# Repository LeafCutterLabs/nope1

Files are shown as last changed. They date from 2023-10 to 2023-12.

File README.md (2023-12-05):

# nope1
OP-1/LMN-3 interface based on the RP2040.<br>
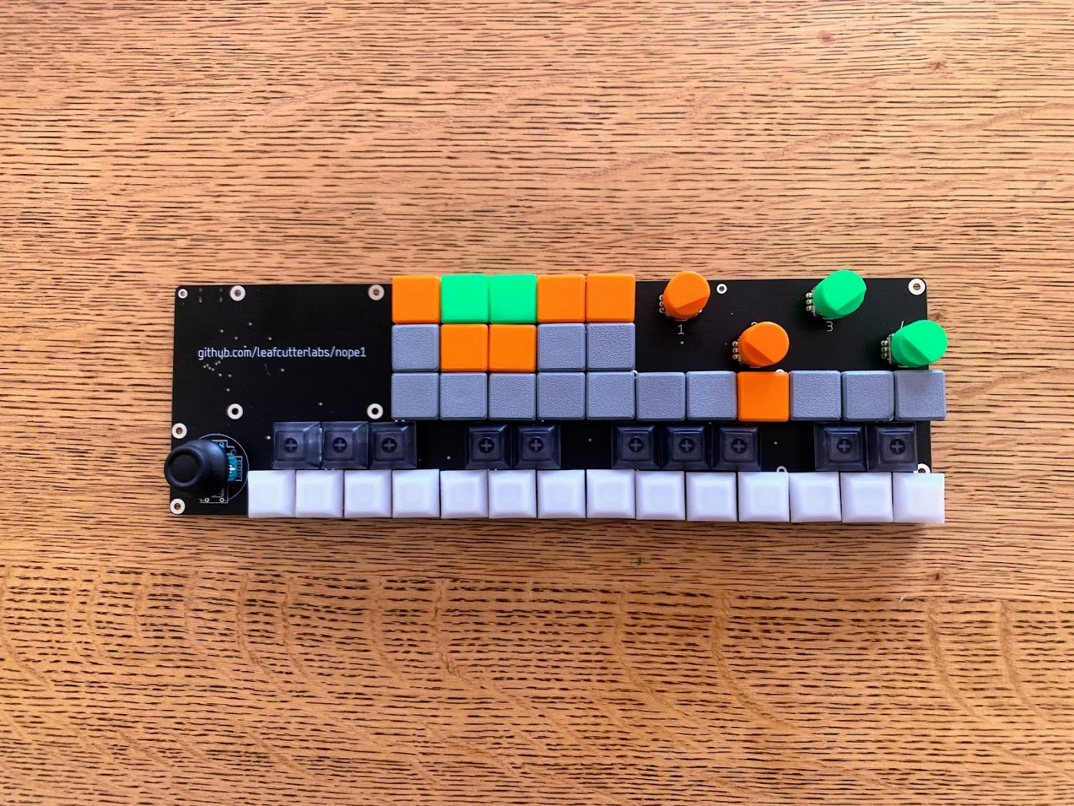
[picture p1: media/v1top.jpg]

Current QMK firmware is very basic (only midi keyboard implemented 53-76 and the LMN-3 CC signals, encoder are now working in vial! analog is not working)<br>
Joystick Analog pins: 26, 27<br>
Known Issues:<br>
	-Joystick switch trace is not connected<br>
 ToDo:<br>
 	-Get Vial running - DONE

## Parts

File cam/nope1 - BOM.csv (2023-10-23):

qty | designator | footprint | comment | lcsc | Value | Device | Package | Parts | Description | BOM | PROD_ID | REV
1 | USBJACK | USB-C-16P |  | C167321 |  |  |  |  | USB Type C 16Pin Connector |  | CONN-14122
9 | C6, C7, C9, C11, C12, C13, C14, C15, C16 | 0603-NO | 0.1uF |  |  |  |  |  | Ceramic Capacitors
4 | R1, R3, R4, R5 | 0603-NO | 10K |  |  |  |  |  | Resistors
3 | C1, C4, C5 | 0805-NO | 10uF |  |  |  |  |  | Ceramic Capacitors
1 | Y1 | RESONATOR3225 | 12MHz | C93234 |  |  |  |  | Various standard crystals. Proven footprints.
2 | R6, R11 | 0603-NO | 1K |  |  |  |  |  | Resistors
50 | U$13, U$14, U$15, U$17, U$18, U$19, U$20, U$21, U$22, U$23, U$24, U$26, U$27, U$28, U$29, U$30, U$31, U$32, U$33, U$54, U$59, U$63, U$68, U$69, U$70, U$71, U$94, U$95, U$96, U$97, U$99, U$100, U$101, U$102, U$103, U$104, U$105, U$106, U$108, U$109, U$110, U$111, U$134, U$135, U$136, U$137, U$139, U$140, U$141, U$142 | SOD-323SLIM | 1N4148WS
2 | C8, C10 | 0603-NO | 1uF |  |  |  |  |  | Ceramic Capacitors
2 | C2, C3 | 0603-NO | 22pF |  |  |  |  |  | Ceramic Capacitors
2 | R9, R10 | 0603-NO | 27 |  |  |  |  |  | Resistors
1 | U1 | SOIC8_208MIL | 2MB Flash | C97521 |  |  |  |  | SOIC8 SPI Flash
2 | R12, R13 | 0603-NO | 5.1K |  |  |  |  |  | Resistors
1 | U2 | SOT23-5@1 | AP2112-3.3 | C134139 |  |  |  |  | SOT23-5 Fixed Voltage Regulators
45 | SW00, SW01, SW02, SW03, SW04, SW09, SW10, SW11, SW12, SW13, SW14, SW15, SW16, SW17, SW18, SW19, SW20, SW21, SW22, SW23, SW24, SW25, SW26, SW27, SW28, SW29, SW30, SW31, SW32, SW33, SW34, SW35, SW36, SW37, SW38, SW39, SW41, SW42, SW43, SW44, SW45, SW46, SW47, SW48, SW49 | CHERRY-SOCKET5 | CHERRY-SOCKET7SOCKET5 | C5156480
4 | U$38, U$39, U$62, U$64 | FIDUCIAL_1MM | FIDUCIAL_1MM |  |  |  |  |  | Fiducial Alignment Points | EXCLUDE
1 | U$34 | JOYSTICKCOMBO | JOYSTICKCOMBO
15 | U$1, U$2, U$3, U$4, U$5, U$6, U$7, U$8, U$9, U$10, U$11, U$12, U$16, U$25, U$78 | M2MOUNT | M2MOUNT
8 | U$65, U$66, U$67, U$72, U$74, U$75, U$76, U$77 | M2SOLDER | M2MOUNTSOLDERMOUNT | C2928180
1 | D4 | SOD-123 | MBR540 | C8598
1 | U$73 | PI4 | PI4
4 | ROT0, ROT1, ROT2, ROT3 | ROTARY_ENC_SLOT | ROTARYENCODER_UNIVERSALSLOT
1 | IC1 | QFN56_7MM_REDUCEDEPAD | RP2040_QFN56
2 | RST, USB | TACTILE_SWITCH_SMD | SWITCH-MOMENTARY-2SMD | C318884 |  |  |  |  | Various NO switches- pushbuttons, reed, etc |  | SWCH-08247

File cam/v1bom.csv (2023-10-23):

Qty | Value | Device | Package | Parts | Description | BOM | PROD_ID | REV
1 |  | USB_C16PIN | USB-C-16P | USBJACK | USB Type C 16Pin Connector |  | CONN-14122
9 | 0.1uF | CAP_CERAMIC0603_NO | 0603-NO | C6, C7, C9, C11, C12, C13, C14, C15, C16 | Ceramic Capacitors
4 | 10K | RESISTOR_0603_NOOUT | 0603-NO | R1, R3, R4, R5 | Resistors
1 | 10uF | CAP_CERAMIC0805-NOOUTLINE | 0805-NO | C5 | Ceramic Capacitors
1 | 10µF | CAP_CERAMIC0805-NOOUTLINE | 0805-NO | C1 | Ceramic Capacitors
1 | 10µF | CAP_CERAMIC0805-NOOUTLINE | 0805-NO | C4 | Ceramic Capacitors |  |  | A
1 | 12MHz | CRYSTAL | RESONATOR3225 | Y1 | Various standard crystals. Proven footprints.
2 | 1K | RESISTOR_0603_NOOUT | 0603-NO | R6, R11 | Resistors
50 | 1N4148WS | 1N4148WS | SOD-323SLIM | U$13, U$14, U$15, U$17, U$18, U$19, U$20, U$21, U$22, U$23, U$24, U$26, U$27, U$28, U$29, U$30, U$31, U$32, U$33, U$54, U$59, U$63, U$68, U$69, U$70, U$71, U$94, U$95, U$96, U$97, U$99, U$100, U$101, U$102, U$103, U$104, U$105, U$106, U$108, U$109, U$110, U$111, U$134, U$135, U$136, U$137, U$139, U$140, U$141, U$142
2 | 1uF | CAP_CERAMIC0603_NO | 0603-NO | C8, C10 | Ceramic Capacitors
2 | 22pF | CAP_CERAMIC0603_NO | 0603-NO | C2, C3 | Ceramic Capacitors
2 | 27 | RESISTOR_0603_NOOUT | 0603-NO | R9, R10 | Resistors
1 | 2MB Flash | SPIFLASH_8PIN208MIL | SOIC8_208MIL | U1 | SOIC8 SPI Flash
2 | 5.1K | RESISTOR_0603_NOOUT | 0603-NO | R12, R13 | Resistors
1 | AP2112-3.3 | VREG_SOT23-5 | SOT23-5@1 | U2 | SOT23-5 Fixed Voltage Regulators
45 | CHERRY-SOCKET7SOCKET5 | CHERRY-SOCKET7SOCKET5 | CHERRY-SOCKET5 | SW00, SW01, SW02, SW03, SW04, SW09, SW10, SW11, SW12, SW13, SW14, SW15, SW16, SW17, SW18, SW19, SW20, SW21, SW22, SW23, SW24, SW25, SW26, SW27, SW28, SW29, SW30, SW31, SW32, SW33, SW34, SW35, SW36, SW37, SW38, SW39, SW41, SW42, SW43, SW44, SW45, SW46, SW47, SW48, SW49
4 | FIDUCIAL_1MM | FIDUCIAL_1MM | FIDUCIAL_1MM | U$38, U$39, U$62, U$64 | Fiducial Alignment Points | EXCLUDE
1 | JOYSTICKCOMBO | JOYSTICKCOMBO | JOYSTICKCOMBO | U$34
15 | M2MOUNT | M2MOUNT | M2MOUNT | U$1, U$2, U$3, U$4, U$5, U$6, U$7, U$8, U$9, U$10, U$11, U$12, U$16, U$25, U$78
8 | M2MOUNTSOLDERMOUNT | M2MOUNTSOLDERMOUNT | M2SOLDER | U$65, U$66, U$67, U$72, U$74, U$75, U$76, U$77
1 | MBR540 | DIODE-SCHOTTKYSOD-123 | SOD-123 | D4
1 | PI4 | PI4 | PI4 | U$73
4 | ROTARYENCODER_UNIVERSALSLOT | ROTARYENCODER_UNIVERSALSLOT | ROTARY_ENC_SLOT | ROT0, ROT1, ROT2, ROT3
1 | RP2040_QFN56 | RP2040_QFN56 | QFN56_7MM_REDUCEDEPAD | IC1
2 | SWITCH-MOMENTARY-2SMD | SWITCH-MOMENTARY-2SMD | TACTILE_SWITCH_SMD | RST, USB | Various NO switches- pushbuttons, reed, etc |  | SWCH-08247

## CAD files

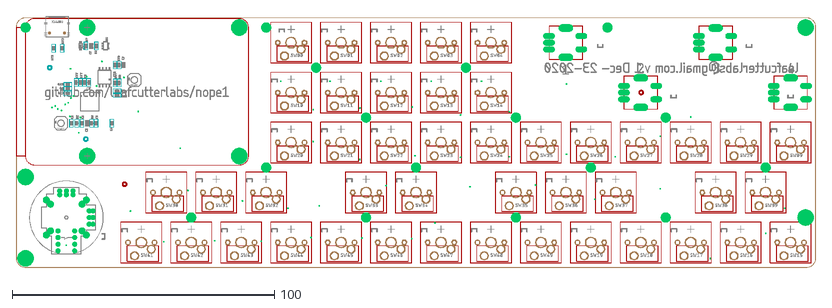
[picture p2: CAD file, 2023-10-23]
cad/v1.dxf
305.0 x 95.9

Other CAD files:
cad/v1CLEAN.dxf

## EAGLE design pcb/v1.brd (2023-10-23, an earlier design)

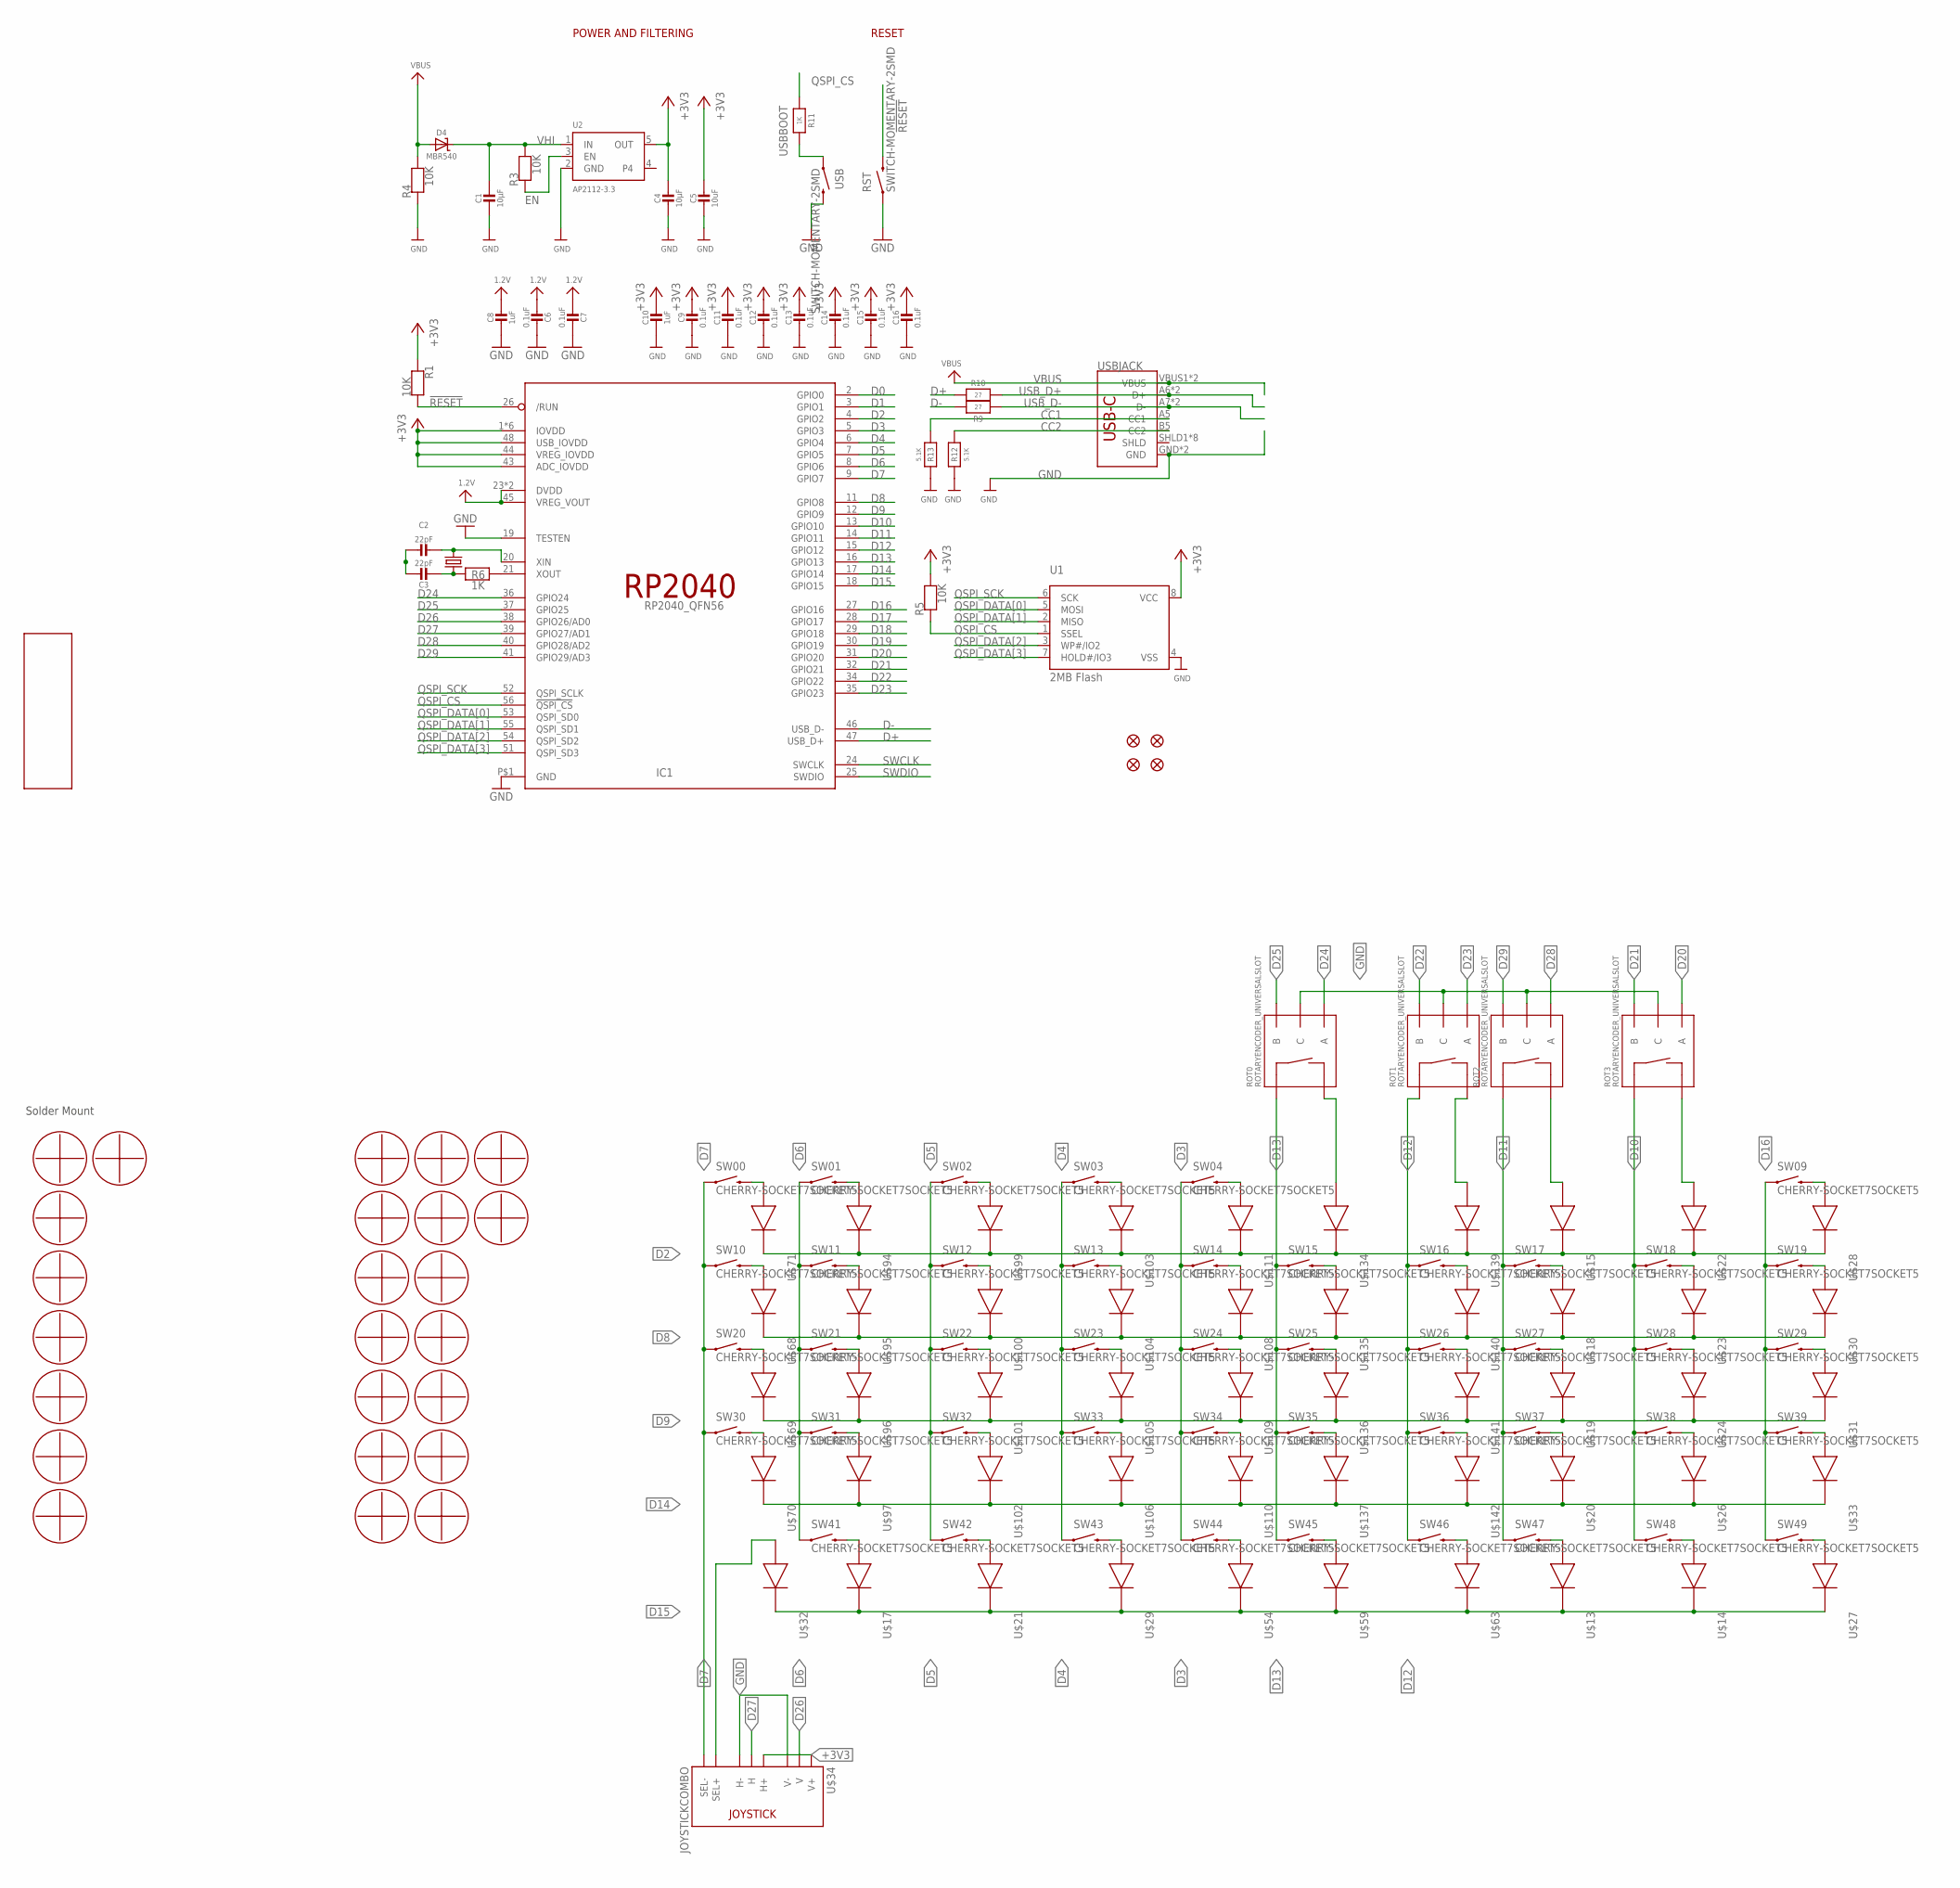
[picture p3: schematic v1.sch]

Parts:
C1, C4: 10µF; 0805-NO
C2, C3: 22pF; 0603-NO
C5: 10uF; 0805-NO
C6, C7, C9, C11, C12, C13, C14, C15, C16: 0.1uF; 0603-NO
C8, C10: 1uF; 0603-NO
D4: MBR540; SOD-123
IC1: RP2040_QFN56; QFN56_7MM_REDUCEDEPAD
R1, R3, R4, R5: 10K; 0603-NO
R6, R11: 1K; 0603-NO
R9, R10: 27; 0603-NO
R12, R13: 5.1K; 0603-NO
ROT0, ROT1, ROT2, ROT3: ROTARYENCODER_UNIVERSALSLOT; ROTARY_ENC_SLOT
RST: SWITCH-MOMENTARY-2SMD; TACTILE_SWITCH_SMD
SW00, SW01, SW02, SW03, SW04, SW09, SW10, SW11, SW12, SW13, SW14, SW15, SW16, SW17, SW18, SW19, SW20, SW21, SW22, SW23, SW24, SW25, SW26, SW27, SW28, SW29, SW30, SW31, SW32, SW33, SW34, SW35, SW36, SW37, SW38, SW39, SW41, SW42, SW43, SW44, SW45, SW46, SW47, SW48, SW49: CHERRY-SOCKET7SOCKET5; CHERRY-SOCKET5
U1: 2MB Flash; SOIC8_208MIL
U2: AP2112-3.3; SOT23-5@1
U$1, U$2, U$3, U$4, U$5, U$6, U$7, U$8, U$9, U$10, U$11, U$12, U$16, U$25, U$78, U$79: M2MOUNT
U$13, U$14, U$15, U$17, U$18, U$19, U$20, U$21, U$22, U$23, U$24, U$26, U$27, U$28, U$29, U$30, U$31, U$32, U$33, U$54, U$59, U$63, U$68, U$69, U$70, U$71, U$94, U$95, U$96, U$97, U$99, U$100, U$101, U$102, U$103, U$104, U$105, U$106, U$108, U$109, U$110, U$111, U$134, U$135, U$136, U$137, U$139, U$140, U$141, U$142: 1N4148WS; SOD-323SLIM
U$34: JOYSTICKCOMBO
U$38, U$39, U$62, U$64: FIDUCIAL_1MM
U$65, U$66, U$67, U$72, U$74, U$75, U$76, U$77: M2MOUNTSOLDERMOUNT; M2SOLDER
U$73: PI4
USB: SWITCH-MOMENTARY-2SMD; TACTILE_SWITCH_SMD
USBJACK: USB_C16PIN; USB-C-16P
Y1: 12MHz; RESONATOR3225

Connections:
1.2V: C6.2, C7.2, C8.1, IC1.23 (DVDD), IC1.45 (VREG_VOUT), IC1.50 (DVDD)
!RESET: IC1.26 (/RUN), R1.2, RST.3 (2)
+3V3: C4.1, C5.1, C9.1, C10.1, C11.1, C12.1, C13.1, C14.1, C15.1, C16.1, IC1.1 (IOVDD), IC1.10 (IOVDD), IC1.22 (IOVDD), IC1.33 (IOVDD), IC1.42 (IOVDD), IC1.43 (ADC_IOVDD), IC1.44 (VREG_IOVDD), IC1.48 (USB_IOVDD), IC1.49 (IOVDD), R1.1, R5.2, U1.8 (VCC), U2.5 (OUT), U$34.H1 (H+), U$34.HS1 (H+), U$34.V1 (V+), U$34.VS1 (V+)
CC1: R13.2, USBJACK.A5 (CC1)
CC2: R12.2, USBJACK.B5 (CC2)
D0: IC1.2 (GPIO0)
D1: IC1.3 (GPIO1)
D2: IC1.4 (GPIO2), U$15.GND (CAT), U$22.GND (CAT), U$28.GND (CAT), U$71.GND (CAT), U$94.GND (CAT), U$99.GND (CAT), U$103.GND (CAT), U$111.GND (CAT), U$134.GND (CAT), U$139.GND (CAT)
D3: IC1.5 (GPIO3), SW04.A (1), SW14.A (1), SW24.A (1), SW34.A (1), SW44.A (1)
D4: IC1.6 (GPIO4), SW03.A (1), SW13.A (1), SW23.A (1), SW33.A (1), SW43.A (1)
D5: IC1.7 (GPIO5), SW02.A (1), SW12.A (1), SW22.A (1), SW32.A (1), SW42.A (1)
D6: IC1.8 (GPIO6), SW01.A (1), SW11.A (1), SW21.A (1), SW31.A (1), SW41.A (1)
D7: IC1.9 (GPIO7), SW00.A (1), SW10.A (1), SW20.A (1), SW30.A (1), U$34.B1B (SEL-), U$34.B1B1 (SEL-), U$34.B2B (SEL-), U$34.B2B1 (SEL-)
D8: IC1.11 (GPIO8), U$18.GND (CAT), U$23.GND (CAT), U$30.GND (CAT), U$68.GND (CAT), U$95.GND (CAT), U$100.GND (CAT), U$104.GND (CAT), U$108.GND (CAT), U$135.GND (CAT), U$140.GND (CAT)
D9: IC1.12 (GPIO9), U$19.GND (CAT), U$24.GND (CAT), U$31.GND (CAT), U$69.GND (CAT), U$96.GND (CAT), U$101.GND (CAT), U$105.GND (CAT), U$109.GND (CAT), U$136.GND (CAT), U$141.GND (CAT)
D10: IC1.13 (GPIO10), ROT3.SW+, SW18.A (1), SW28.A (1), SW38.A (1), SW48.A (1)
D11: IC1.14 (GPIO11), ROT2.SW+, SW17.A (1), SW27.A (1), SW37.A (1), SW47.A (1)
D12: IC1.15 (GPIO12), ROT1.SW+, SW16.A (1), SW26.A (1), SW36.A (1), SW46.A (1)
D13: IC1.16 (GPIO13), ROT0.SW+, SW15.A (1), SW25.A (1), SW35.A (1), SW45.A (1)
D14: IC1.17 (GPIO14), U$20.GND (CAT), U$26.GND (CAT), U$33.GND (CAT), U$70.GND (CAT), U$97.GND (CAT), U$102.GND (CAT), U$106.GND (CAT), U$110.GND (CAT), U$137.GND (CAT), U$142.GND (CAT)
D15: IC1.18 (GPIO15), U$13.GND (CAT), U$14.GND (CAT), U$17.GND (CAT), U$21.GND (CAT), U$27.GND (CAT), U$29.GND (CAT), U$32.GND (CAT), U$54.GND (CAT), U$59.GND (CAT), U$63.GND (CAT)
D16: IC1.27 (GPIO16), SW09.A (1), SW19.A (1), SW29.A (1), SW39.A (1), SW49.A (1)
D17: IC1.28 (GPIO17)
D18: IC1.29 (GPIO18)
D19: IC1.30 (GPIO19)
D20: IC1.31 (GPIO20), ROT3.A
D21: IC1.32 (GPIO21), ROT3.B
D22: IC1.34 (GPIO22), ROT1.B
D23: IC1.35 (GPIO23), ROT1.A
D24: IC1.36 (GPIO24), ROT0.A
D25: IC1.37 (GPIO25), ROT0.B
D26: IC1.38 (GPIO26/AD0), U$34.V2 (V), U$34.VS2 (V)
D27: IC1.39 (GPIO27/AD1), U$34.H2 (H), U$34.HS2 (H)
D28: IC1.40 (GPIO28/AD2), ROT2.A
D29: IC1.41 (GPIO29/AD3), ROT2.B
D+: IC1.47 (USB_D+), R10.2
D-: IC1.46 (USB_D-), R9.2
EN: R3.1, U2.3 (EN)
GND: C1.2, C2.1, C3.1, C4.2, C5.2, C6.1, C7.1, C8.2, C9.2, C10.2, C11.2, C12.2, C13.2, C14.2, C15.2, C16.2, IC1.19 (TESTEN), IC1.P$1 (GND), R4.1, R12.1, R13.1, ROT0.C, ROT1.C, ROT2.C, ROT3.C, RST.1, U1.4 (VSS), U2.2 (GND), U$34.H3 (H-), U$34.HS3 (H-), U$34.V3 (V-), U$34.VS3 (V-), USB.3 (2), USBJACK.GND, USBJACK.GND2 (GND)
unnamed: U$32.SIGNAL (ANO), U$34.B1A (SEL+), U$34.B1A1 (SEL+), U$34.B2A (SEL+), U$34.B2A1 (SEL+)
unnamed: SW47.B (2), U$13.SIGNAL (ANO)
unnamed: SW48.B (2), U$14.SIGNAL (ANO)
unnamed: ROT2.SW-, U$15.SIGNAL (ANO)
unnamed: SW17.B (2), U$18.SIGNAL (ANO)
unnamed: SW27.B (2), U$19.SIGNAL (ANO)
unnamed: SW37.B (2), U$20.SIGNAL (ANO)
unnamed: SW41.B (2), U$17.SIGNAL (ANO)
unnamed: ROT3.SW-, U$22.SIGNAL (ANO)
unnamed: SW18.B (2), U$23.SIGNAL (ANO)
unnamed: SW28.B (2), U$24.SIGNAL (ANO)
unnamed: SW38.B (2), U$26.SIGNAL (ANO)
unnamed: SW49.B (2), U$27.SIGNAL (ANO)
unnamed: SW09.B (2), U$28.SIGNAL (ANO)
unnamed: SW42.B (2), U$21.SIGNAL (ANO)
unnamed: SW19.B (2), U$30.SIGNAL (ANO)
unnamed: SW29.B (2), U$31.SIGNAL (ANO)
unnamed: SW39.B (2), U$33.SIGNAL (ANO)
unnamed: SW00.B (2), U$71.SIGNAL (ANO)
unnamed: C2.2, IC1.20 (XIN), Y1.P3 (2)
unnamed: SW43.B (2), U$29.SIGNAL (ANO)
unnamed: SW44.B (2), U$54.SIGNAL (ANO)
unnamed: C3.2, R6.1, Y1.P1 (1)
unnamed: IC1.21 (XOUT), R6.2
unnamed: SW45.B (2), U$59.SIGNAL (ANO)
unnamed: SW10.B (2), U$68.SIGNAL (ANO)
unnamed: SW20.B (2), U$69.SIGNAL (ANO)
unnamed: SW30.B (2), U$70.SIGNAL (ANO)
unnamed: SW46.B (2), U$63.SIGNAL (ANO)
unnamed: SW01.B (2), U$94.SIGNAL (ANO)
unnamed: SW11.B (2), U$95.SIGNAL (ANO)
unnamed: SW21.B (2), U$96.SIGNAL (ANO)
unnamed: SW31.B (2), U$97.SIGNAL (ANO)
unnamed: SW02.B (2), U$99.SIGNAL (ANO)
unnamed: SW12.B (2), U$100.SIGNAL (ANO)
unnamed: SW22.B (2), U$101.SIGNAL (ANO)
unnamed: SW32.B (2), U$102.SIGNAL (ANO)
unnamed: SW14.B (2), U$108.SIGNAL (ANO)
unnamed: SW24.B (2), U$109.SIGNAL (ANO)
unnamed: SW34.B (2), U$110.SIGNAL (ANO)
unnamed: SW03.B (2), U$103.SIGNAL (ANO)
unnamed: SW13.B (2), U$104.SIGNAL (ANO)
unnamed: SW23.B (2), U$105.SIGNAL (ANO)
unnamed: SW33.B (2), U$106.SIGNAL (ANO)
unnamed: SW04.B (2), U$111.SIGNAL (ANO)
unnamed: ROT0.SW-, U$134.SIGNAL (ANO)
unnamed: SW15.B (2), U$135.SIGNAL (ANO)
unnamed: SW25.B (2), U$136.SIGNAL (ANO)
unnamed: SW35.B (2), U$137.SIGNAL (ANO)
unnamed: ROT1.SW-, U$139.SIGNAL (ANO)
unnamed: SW16.B (2), U$140.SIGNAL (ANO)
unnamed: SW26.B (2), U$141.SIGNAL (ANO)
unnamed: SW36.B (2), U$142.SIGNAL (ANO)
QSPI_CS: IC1.56 (!QSPI_CS), R5.1, R11.1, U1.1 (SSEL)
QSPI_DATA[0]: IC1.53 (QSPI_SD0), U1.5 (MOSI)
QSPI_DATA[1]: IC1.55 (QSPI_SD1), U1.2 (MISO)
QSPI_DATA[2]: IC1.54 (QSPI_SD2), U1.3 (WP#/IO2)
QSPI_DATA[3]: IC1.51 (QSPI_SD3), U1.7 (HOLD#/IO3)
QSPI_SCK: IC1.52 (QSPI_SCLK), U1.6 (SCK)
SWCLK: IC1.24 (SWCLK)
SWDIO: IC1.25 (SWDIO)
USBBOOT: R11.2, USB.1
USB_D+: R10.1, USBJACK.A6 (D+), USBJACK.B6 (D+)
USB_D-: R9.1, USBJACK.A7 (D-), USBJACK.B7 (D-)
VBUS: D4.A, R4.2, USBJACK.VBUS1 (VBUS), USBJACK.VBUS2 (VBUS)
VHI: C1.1, D4.C, R3.2, U2.1 (IN)

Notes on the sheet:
POWER AND FILTERING
RESET
Solder Mount

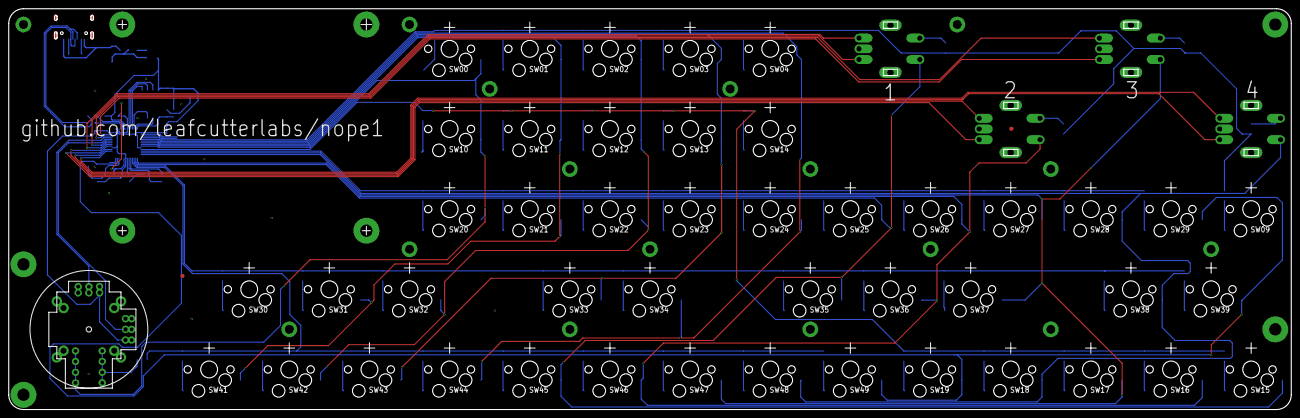
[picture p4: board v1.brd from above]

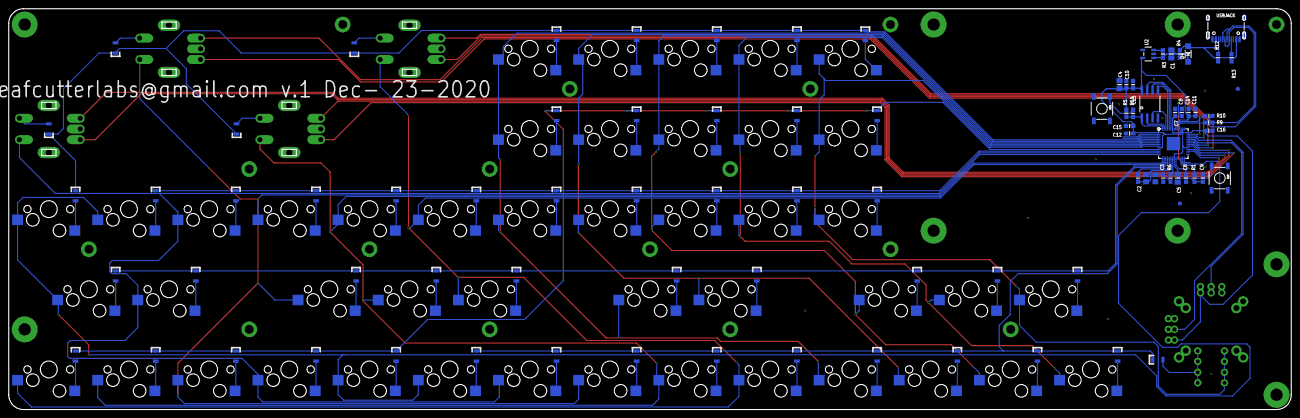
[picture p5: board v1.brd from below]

Board: 2 copper layers, 304.8 x 95.2 mm, 163 parts (94 on the bottom side), 98 nets.

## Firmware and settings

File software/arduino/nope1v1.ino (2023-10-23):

#include <Control_Surface.h>

// Instantiate a MIDI over USB interface.
USBMIDI_Interface midi;

CCPotentiometer pot0 { A0, MIDI_CC::General_Purpose_Controller_1 }; //joystick up/down
CCPotentiometer pot1 { A1, MIDI_CC::General_Purpose_Controller_2 }; //joystick left/right

const int ENCODER_1 = 3;
const int ENCODER_2 = 9;
const int ENCODER_3 = 14;
const int ENCODER_4 = 15;

// Row Pins
const int ROW_0 = 2;
const int ROW_1 = 8;
const int ROW_2 = 9;
const int ROW_3 = 14;
const int ROW_4 = 15;

// Col Pins
const int COL_0 = 7;
const int COL_1 = 6;
const int COL_2 = 5;
const int COL_3 = 4;
const int COL_4 = 3;
const int COL_5 = 13;
const int COL_6 = 12;
const int COL_7 = 11;
const int COL_8 = 10;
const int COL_9 = 16;

CCRotaryEncoder enc1 = {
    {24, 25}, // pins
    {ENCODER_1},         // MIDI address (CC number + optional channel)
    1,      // optional multiplier if the control isn't fast enough
};

CCRotaryEncoder enc2 = {
    {23, 22}, // pins
    {ENCODER_2},         // MIDI address (CC number + optional channel)
    1,      // optional multiplier if the control isn't fast enough
};

CCRotaryEncoder enc3 = {
    {28, 29}, // pins
    {ENCODER_3},         // MIDI address (CC number + optional channel)
    1,      // optional multiplier if the control isn't fast enough
};

CCRotaryEncoder enc4 = {
    {20, 21}, // pins
    {ENCODER_4},         // MIDI address (CC number + optional channel)
    1,      // optional multiplier if the control isn't fast enough
};

const AddressMatrix<3, 10> noteAddresses = {{
                                                {1 ,  1,  1,  1, 1 , 76, 74, 72, 71, 69},
                                                {54, 56, 58, 61, 63, 66, 68, 70, 73, 75},
                                                {1 , 53, 55, 57, 59, 60, 62, 64, 65, 67},  
                                            }};

NoteButtonMatrix<3, 10> noteButtonMatrix = {
    {ROW_2, ROW_3, ROW_4}, // row pins
    {COL_0, COL_1, COL_2, COL_3, COL_4, COL_5, COL_6, COL_7, COL_8, COL_9},    // column pins
    noteAddresses,    // address matrix
    CHANNEL_1,    // channel and cable number
};

void setup() {
    Control_Surface.begin(); // Initialize Control Surface
}

void loop() {
    Control_Surface.loop(); // Update the Control Surface
}

/*
// CC values
const int ENCODER_1 = 3;
const int ENCODER_2 = 9;
const int ENCODER_3 = 14;
const int ENCODER_4 = 15;
const int ENCODER_1_BUTTON = 20;
const int ENCODER_2_BUTTON = 21;
const int ENCODER_3_BUTTON = 22;
const int ENCODER_4_BUTTON = 23;
const int UNDO_BUTTON = 24;
const int TEMPO_BUTTON = 25;
const int SAVE_BUTTON = 26;
const int SETTINGS_BUTTON = 85;
const int TRACKS_BUTTON = 86;
const int MIXER_BUTTON = 88;
const int PLUGINS_BUTTON = 89;
const int MODIFIERS_BUTTON = 90;
const int SEQUENCERS_BUTTON = 102;   
const int LOOP_IN_BUTTON = 103;
const int LOOP_OUT_BUTTON = 104;
const int LOOP_BUTTON = 105;
const int CUT_BUTTON = 106;
const int PASTE_BUTTON = 107;
const int SLICE_BUTTON = 108;
const int RECORD_BUTTON = 109;
const int PLAY_BUTTON = 110;
const int STOP_BUTTON = 111;
const int CONTROL_BUTTON = 112;
const int OCTAVE_CHANGE = 117;
const int PLUS_BUTTON = 118;
const int MINUS_BUTTON = 119;
const int DUMMY = 31;


const AddressMatrix<5, 10> noteAddresses = {{
                                                {50, 51, 52, 53, 54, 55, 56, 57, 58, 59},
                                                {60, 61, 62, 63, 64, 65, 66, 67, 68, 69},
                                                {70, 71, 72, 73, 74, 75, 76, 77, 78, 79},
                                                {80, 81, 82, 83, 84, 85, 86, 87, 88, 89},
                                                {90, 91, 92, 93, 94, 95, 96, 97, 98, 99},  
                                            }};

Bankable::NoteButtonMatrix<2, 14> noteButtonMatrix = {
    transposer,
    {ROW_1, ROW_2, ROW_3, ROW_4, ROW_5}, // row pins
    {COL_0, COL_1, COL_2, COL_3, COL_4, COL_5, COL_6, COL_7, COL_8, COL_9},    // column pins
    noteAddresses,    // address matrix
    CHANNEL_1,    // channel and cable number
};


/*
const int maxTransposition = 4;
const int minTransposition = -1 * maxTransposition;
const int transpositionSemitones = 12;
Transposer<minTransposition, maxTransposition>transposer(transpositionSemitones);

const AddressMatrix<2, 14> noteAddresses = {{
                                                {1, 54, 56, 58, 1, 61, 63, 1, 66, 68, 70, 1, 73, 75},
                                                {53, 55, 57, 59, 60, 62, 64, 65, 67, 69, 71, 72, 74, 76},  
                                            }};

Bankable::NoteButtonMatrix<2, 14> noteButtonMatrix = {
    transposer,
    {ROW_3, ROW_4}, // row pins
    {COL_0, COL_1, COL_2, COL_3, COL_4, COL_5, COL_6, COL_7, COL_8, COL_9, COL_10, COL_11, COL_12, COL_13},    // column pins
    noteAddresses,    // address matrix
    CHANNEL_1,    // channel and cable number
};

// Note that plus and minus buttons need special care since they also control the transposer
// When presses are detected on plus and minus as part of the matrix scanning just send a dummy CC message
// The plus/minus buttons are handled separately as part of updatePlusMinus()
const AddressMatrix<3, 11> ccAddresses = {{
                                              {LOOP_BUTTON, LOOP_IN_BUTTON, LOOP_OUT_BUTTON, DUMMY, DUMMY, DUMMY, ENCODER_1_BUTTON, ENCODER_2_BUTTON, DUMMY, ENCODER_3_BUTTON, ENCODER_4_BUTTON},
                                              {CUT_BUTTON, PASTE_BUTTON, SLICE_BUTTON, SAVE_BUTTON, UNDO_BUTTON, DUMMY, DUMMY, DUMMY, DUMMY, DUMMY, DUMMY},
                                              {CONTROL_BUTTON, RECORD_BUTTON, PLAY_BUTTON, STOP_BUTTON, SETTINGS_BUTTON, TEMPO_BUTTON, MIXER_BUTTON, TRACKS_BUTTON, PLUGINS_BUTTON, MODIFIERS_BUTTON, SEQUENCERS_BUTTON}
                                         }};

CCButtonMatrix<3, 11> ccButtonmatrix = {
    {ROW_0, ROW_1, ROW_2}, // row pins
    {COL_3, COL_4, COL_5, COL_6, COL_7, COL_8, COL_9, COL_10, COL_11, COL_12, COL_13},    // column pins
    ccAddresses,    // address matrix
    CHANNEL_1,    // channel and cable number
};

bool plusPressed = false;
bool minusPressed = false;
bool shiftPressed = false;
bool shouldUpdateOctave = false;

// There is probably a better way, but this is what I thought of first and it works ok ¯\_(ツ)_/¯
// Hard to follow though :/
void updatePlusMinus() {
    // check if shift is down
    // getPrevState uses (col, row)
    if (ccButtonmatrix.getPrevState(0, 2) == 0) {
        shiftPressed = true;
        // Shift is down so send the octave change messages instead of the regular plus/minus ones
        // Check if plus was released
        if (ccButtonmatrix.getPrevState(3, 0) == 0) {
            plusPressed = true;
            
        } else {
            if (plusPressed) {
                if (transposer.getTransposition() < maxTransposition) {
                    transposer.setTransposition(transposer.getTransposition() + 1);
                }
                shouldUpdateOctave = true;
                plusPressed = false;
            }
        }

        // Check if minus was released
        if (ccButtonmatrix.getPrevState(4, 0) == 0) {
            minusPressed = true;
        } else {
            if (minusPressed) {
                if (transposer.getTransposition() > minTransposition) {
                    transposer.setTransposition(transposer.getTransposition() - 1);
                }
                shouldUpdateOctave = true;
                minusPressed = false;
            }
        }

        if (shouldUpdateOctave) {
            // Cant send negative midi values, so we need to remap to only positive values
            map(transposer.getTransposition(), minTransposition, maxTransposition, 0, maxTransposition - minTransposition);
            Control_Surface.sendControlChange(MIDIAddress(OCTAVE_CHANGE, CHANNEL_1), transposer.getTransposition() + maxTransposition);
            shouldUpdateOctave = false;
        }
    } else {
        // Check if plus was pressed/released
        if (ccButtonmatrix.getPrevState(3, 0) == 0) {
            if (!plusPressed) {
                plusPressed = true;
                Control_Surface.sendControlChange(MIDIAddress(PLUS_BUTTON, CHANNEL_1), 127);
            }
            
        } else {
            if (plusPressed) {
                plusPressed = false;
                Control_Surface.sendControlChange(MIDIAddress(PLUS_BUTTON, CHANNEL_1), 0);
            }
        }

        // Check if minus was pressed/released
        if (ccButtonmatrix.getPrevState(4, 0) == 0) {
            if (!minusPressed) {
                minusPressed = true;
                Control_Surface.sendControlChange(MIDIAddress(MINUS_BUTTON, CHANNEL_1), 127);
            }
        } else {
            if (minusPressed) {
                minusPressed = false;
                Control_Surface.sendControlChange(MIDIAddress(MINUS_BUTTON, CHANNEL_1), 0);
            }
        }
    } 
}
*/

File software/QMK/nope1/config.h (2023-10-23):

// Copyright 2022 Stefan Kerkmann
// SPDX-License-Identifier: GPL-2.0-or-later

#pragma once


#define DEBUG_MATRIX_SCAN_RATE

#define QMK_WAITING_TEST_BUSY_PIN GP24
#define QMK_WAITING_TEST_YIELD_PIN GP25

#define RP2040_BOOTLOADER_DOUBLE_TAP_RESET
#define RP2040_BOOTLOADER_DOUBLE_TAP_RESET_LED GP22
#define RP2040_BOOTLOADER_DOUBLE_TAP_RESET_TIMEOUT 500U

#define BACKLIGHT_PWM_CHANNEL RP2040_PWM_CHANNEL_B

#define AUDIO_PIN GP23
#define AUDIO_PWM_DRIVER PWMD0
#define AUDIO_PWM_CHANNEL RP2040_PWM_CHANNEL_A

#define ADC_PIN GP29

#define MIDI_ADVANCED

#define ENCODERS_PAD_A { GP24, GP23, GP28, GP20}
#define ENCODERS_PAD_B { GP25, GP22, GP29, GP21}
#define ENCODER_RESOLUTION 2

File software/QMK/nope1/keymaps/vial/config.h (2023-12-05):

/* SPDX-License-Identifier: GPL-2.0-or-later */

#pragma once

#define MIDI_ADVANCED
#define VIAL_KEYBOARD_UID {0x8C, 0xBC, 0xEA, 0x9B, 0xFD, 0x3F, 0x8B, 0xE0}

#define DEBUG_MATRIX_SCAN_RATE

#define RP2040_BOOTLOADER_DOUBLE_TAP_RESET
#define RP2040_BOOTLOADER_DOUBLE_TAP_RESET_LED GP22
#define RP2040_BOOTLOADER_DOUBLE_TAP_RESET_TIMEOUT 500U

#define BACKLIGHT_PWM_CHANNEL RP2040_PWM_CHANNEL_B

#define MIDI_ADVANCED

#define ENCODERS_PAD_A { GP24, GP23, GP28, GP20}
#define ENCODERS_PAD_B { GP25, GP22, GP29, GP21}
#define ENCODER_RESOLUTION 4

//#define WS2812_DI_PIN GP15
//#define RGB_MATRIX_LED_COUNT 57

//#define RGB_MATRIX_FRAMEBUFFER_EFFECTS
//#define RGB_MATRIX_KEYPRESSES

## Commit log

2023-10-23 init
    first push
    [nope1 - BOM.csv, v1.brd, v1.dxf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]
2023-12-05 Updated VIAL firmware
    Full encoder support in VIAL

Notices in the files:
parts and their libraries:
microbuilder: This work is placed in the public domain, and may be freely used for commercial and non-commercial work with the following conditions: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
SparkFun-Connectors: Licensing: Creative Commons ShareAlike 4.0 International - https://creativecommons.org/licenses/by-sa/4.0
